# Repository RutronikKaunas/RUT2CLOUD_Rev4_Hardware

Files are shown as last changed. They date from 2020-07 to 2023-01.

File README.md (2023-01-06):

# RUT2CLOUD Evaluation Kit STM32WB55

This is the unreleased Rutronik development kit RUT2CLOUD Rev4. This board is featuring the GL865-DUAL 2G modem which is bundled together with the SL876Q5-A GNSS module and an STM32WB55 system-on-chip microcontroller that acts as a host of the system.

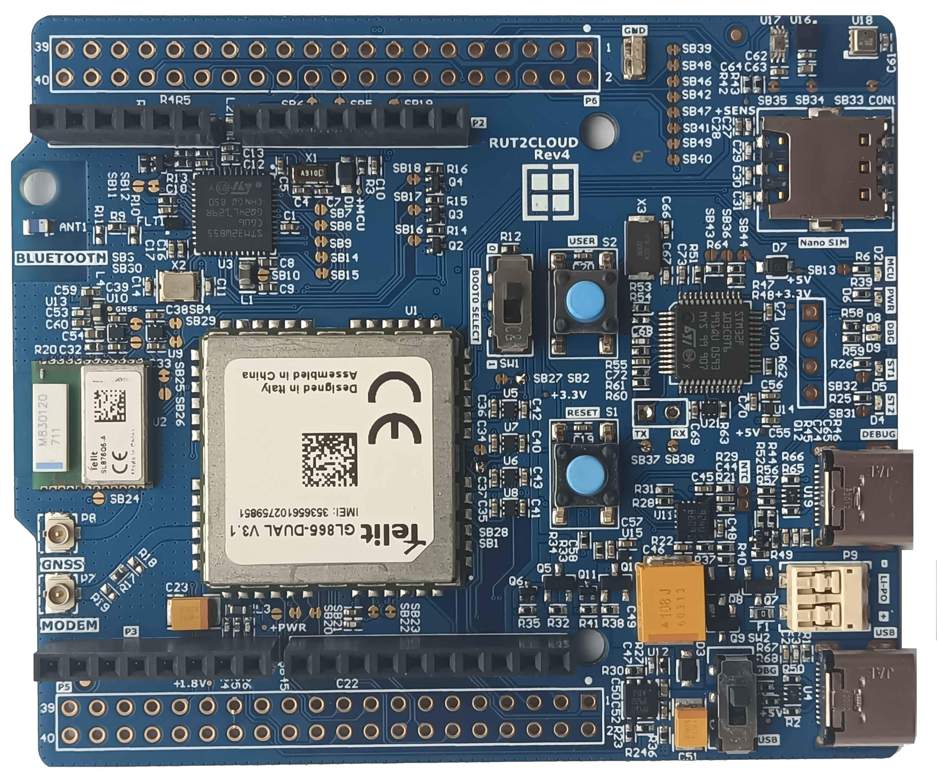
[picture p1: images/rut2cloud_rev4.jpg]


## Features

-   Telit GL865 DUAL V3.1 Cellular Modem (NL865 4G optional).
-   Telit SL876Q5-A GNSS Module.
-   Nano SIM card slot.
-   Ceramic Chip BLE Antenna ANT2012LL00R2400A.
-   STM32WB55CGU6 - Multiprotocol wireless 32-bit MCU Arm®-based Cortex®-M4  with FPU, Bluetooth® 5 and 802.15.4 radio solution.
-   L6924U - USB-compatible battery charger system with integrated power switch for Li-Ion/Li-Polymer.
-  LD39200PUR - 2 A high PSRR ultra-low drop linear regulator with reverse current protection.
-  STLQ020J18R - 1.8V 200 mA ultra-low quiescent current LDO.
-  STLQ020J33R – 3.3V 200 mA ultra-low quiescent current LDO.
-   LIS2DW12TR - MEMS digital output motion sensor: high-performance ultra-low-power 3-axis  "femto" accelerometer.
-   BH1730FVC-TR - Digital 16bit Serial Output Type  Ambient Light Sensor IC.
-   BME280 - Pressure, Humidity, Temperature Sensor.
-  
   Onboard ST-Link Debugger.

## Legal Disclaimer

The evaluation board including the software is for testing purposes only and, because it has limited functions and limited resilience, is not suitable for permanent use under real conditions. If the evaluation board is nevertheless used under real conditions, this is done at one’s responsibility; any liability of Rutronik is insofar excluded. 

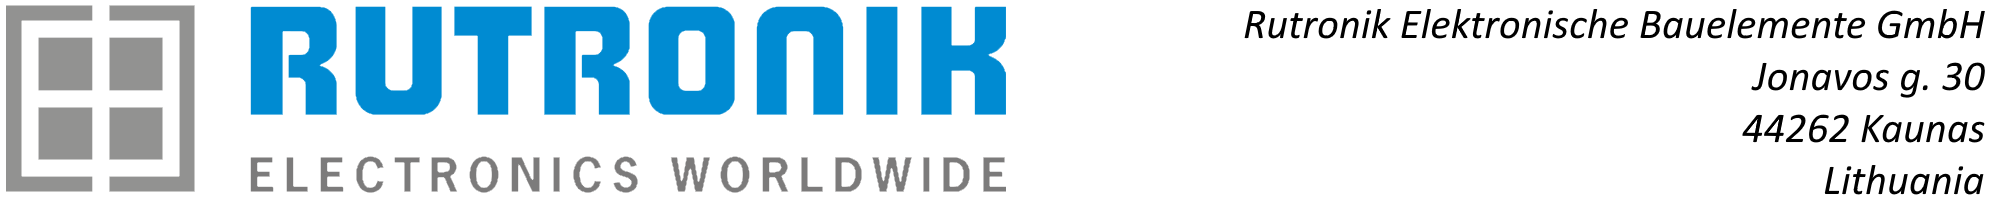
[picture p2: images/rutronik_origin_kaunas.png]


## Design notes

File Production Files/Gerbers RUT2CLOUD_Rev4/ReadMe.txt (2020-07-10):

Project RUT2CLOUD_Rev4:
PCB dimensions 82x82.5mm.
4 Layers.
Thickness: 1.55 mm. FR4
Mask color : Blue.
Silkscreen color: White.
Finish: Immersion GOLD

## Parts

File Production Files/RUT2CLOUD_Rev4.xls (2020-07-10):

 | RUT2CLOUD BOM Rev4
Part Description | Designator | Value | Footprint | Quantity | Manufacturer | Manufacturer Part No. | Specification | Supplier | Supplier part number | Link
Ceramic Chip Antenna | ANT1 | ANT2012LL00R2400A | YEGEO_BT_Antena_0805 | 1 | YAGEO | ANT2012LL00R2400A | 2.4 – 2.5 GHZ | Rutronik | WIREAC1413 | https://www.rutronik24.com/product/yageo/ant2012ll00r2400a/42235.html
Ceramic Capacitor | C1, C5, C13, C15, C16, C18, C21, C25, C28, C32, C33, C34, C35, C36, C37, C38, C39, C40, C41, C42, C43, C61, C62, C64, C69, C70, C71, C72, C73 | 220nF | C0402 | 29 | YAGEO | CC0402JRNPO9BN100, CC0402KRX5R5BB224 | NP0, 6.3V, 5%, X5R, 6.3V, 10% | Rutronik | KKK14556, KKK23148 | https://www.rutronik24.com/product/yageo/cc0402jrnpo9bn100/29735.html, https://www.rutronik24.com/product/yageo/cc0402krx5r5bb224/3611951.html
Ceramic Capacitor | C2, C74 | 4.7nF | C0402 | 2 | YAGEO | CC0402JRNPO9BN100 | NP0, 6.3V, 5% | Rutronik | KKK14556 | https://www.rutronik24.com/product/yageo/cc0402jrnpo9bn100/29735.html
Ceramic Capacitor | C3, C22, C24, C26, C27, C29, C30, C31, C53, C65 | 33pF | C0402 | 10 | YAGEO, AVX | CC0402JRNPO9BN100, 04025A330JAT2A | NP0, 6.3V, 5% | Rutronik | KKK14556, KKK13594 | https://www.rutronik24.com/product/yageo/cc0402jrnpo9bn100/29735.html, https://www.rutronik24.com/product/avx/04025a330jat2a/3692730.html
Ceramic Capacitor | C4, C7, C11, C14, C47 | 10pF | C0402 | 5 | YAGEO | CC0402JRNPO9BN100 | NP0, 6.3V, 5% | Rutronik | KKK14556 | https://www.rutronik24.com/product/yageo/cc0402jrnpo9bn100/29735.html
Ceramic Capacitor | C8, C9 | 4.7uF | C0402 | 2 | YAGEO | CC0402JRNPO9BN100 | NP0, 6.3V, 5% | Rutronik | KKK14556 | https://www.rutronik24.com/product/yageo/cc0402jrnpo9bn100/29735.html
Ceramic Capacitor | C10 | 100nF | C0402 | 1 | YAGEO | CC0402JRNPO9BN100 | NP0, 6.3V, 5% | Rutronik | KKK14556 | https://www.rutronik24.com/product/yageo/cc0402jrnpo9bn100/29735.html
Ceramic Capacitor | C12, C17 | 100pF | C0402 | 2 | YAGEO | CC0402JRNPO9BN100 | NP0, 6.3V, 5% | Rutronik | KKK14556 | https://www.rutronik24.com/product/yageo/cc0402jrnpo9bn100/29735.html
Ceramic Capacitor | C19, C20, C46 | 10nF | C0402 | 3 | Samsung Electronics | CL05B103KB5NNNC, CL05B102KB5NNND | X5R, 6.3V, 10% | Rutronik | KKK21418, KKK22306 | https://www.rutronik24.com/product/samsung+em/cl05b103kb5nnnc/6075254.html, https://www.rutronik24.com/product/samsung+em/cl05b102kb5nnnd/7450031.html
Tantalum Capacitor | C23, C51 | 100uF | Case-B | 2 | AVX | TPSB107K006R0400 | 6,3V 20% | Rutronik | KTA5959 | https://www.rutronik24.com/product/avx/tpsb107k006r0400/3688840.html
Ceramic Capacitor | C44, C45, C48, C52, C55, C56, C57, C58, C59, C60 | 1uF | C0402 | 10 | Samsung Electronics | CL05B102KB5NNND, CL05A106MP5NUNC, CL05A225MQ5NNNC | X5R, 6.3V, 10%, X5R, 6.3V, 20% | Rutronik | KKK22306, KKS2857, KKS2678 | https://www.rutronik24.com/product/samsung+em/cl05b102kb5nnnd/7450031.html, https://www.rutronik24.com/product/samsung+em/cl05a106mp5nunc/32408.html, https://www.rutronik24.com/product/samsung+em/cl05a225mq5nnnc/32280.html
Tantalum Capacitor | C49 | 1000uFx6.3V | 7361-38 | 1 | AVX | TPSV108M006R0050 | 6,3V 20% | Rutronik | TPSV108M006R0050 | https://www.rutronik24.com/product/avx/tpsv108m006r0050/11647835.html
Ceramic Capacitor | C50, C54, C63 | 10uF | C0402 | 3 | Samsung Electronics, YAGEO | CL05A106MP5NUNC, CC0402KRX5R5BB224 | X5R, 6.3V, 20%, X5R, 6.3V, 10% | Rutronik | KKS2857, KKK23148 | https://www.rutronik24.com/product/samsung+em/cl05a106mp5nunc/32408.html, https://www.rutronik24.com/product/yageo/cc0402krx5r5bb224/3611951.html
Ceramic Capacitor | C66, C67, C68 | 20pF | C0402 | 3 | YAGEO | CC0402JRNPO9BN100 | NP0, 6.3V, 5% | Rutronik | KKK14556 | https://www.rutronik24.com/product/yageo/cc0402jrnpo9bn100/29735.html
Nano SIM Card Connector | CON1 | CH03-KB060-HAR | CH03-KB | 1 | GradConn | CH03-KB060-HAR | Nano, 6 pins | Rutronik | SIMCRD1002 | https://www.rutronik24.com/product/gradconn/ch03-kb060-har/7026333.html
Low VF Schottky Barrier Rectifier | D1, D3, D7 | RB168VAM-30 | SOD323 | 3 | ROHM | RB168VAM-30 | 30V, 1A | Rutronik | RB168VAM-30 | http://rohmfs.rohm.com/en/products/databook/datasheet/discrete/diode/schottky_barrier/rb168vam-30tr-e.pdf
Typical SMD LED | D2, D4, D6, D9 | SML-P13PTT86R | PICOLED | 4 | ROHM | SML-P13PTT86R | Green, 20mA | Rutronik | LED26047 | https://www.rutronik24.com/product/rohm/sml-p13ptt86r/11064312.html
Typical SMD LED | D5, D8 | SML-P12UTT86 | PICOLED | 2 | ROHM | SML-P12UTT86 | Red, 20mA | Rutronik | LED24884 | https://www.rutronik24.com/product/rohm/sml-p12utt86/8485748.html
Thick Film Resistor | F1 | 0R | R0603 | 1 | YAGEO | RC0402FR-070RL | 5% 0,063W | Rutronik | WRC53079 | https://www.rutronik24.com/product/yageo/rc0402fr-070rl/5183530.html
2.4 GHz low pass filter | FLT1 | MLPF-WB55-01E3 | Bumpless CSP | 1 | STMicroelectronics | MLPF-WB55-01E3 | 2.4GHz, CSP | Digi-Key | 497-19088-1-ND | https://www.digikey.com/product-detail/en/stmicroelectronics/MLPF-WB55-01E3/497-19088-1-ND/10057128
Inductor | L1 | 10uH | L0805 | 1 | muRata | LQM21FN100M70L | 100mA | Rutronik | IND8474 | https://www.rutronik24.com/product/murata/lqm21fn100m70l/25672.html
Ferrite Bead | L2, L3, L4 | BLM18PG121SH1D | L0603 | 3 | muRata | BLM18PG121SH1D | 120R, 2A | Rutronik | FE3867 | https://www.rutronik24.com/product/murata/blm18pg121sh1d/5885588.html
Arduino Stackable Header Kit | P1 | PRT-11417 | HDR1X10 | 1 | SparkFun Electronics | PRT-11417 | 10 pins | Digi-Key | 1568-1413-ND
U.FL Connector | P7, P8 | U.FL-R-SMT-1(10) | U.FL_Connector_Male | 2 | HIROSE | U.FL-R-SMT-1(10) | Male | Rutronik | COREC23028 | https://www.hirose.com/product/en/products/U.FL/U.FL-R-SMT-1%2810%29/
Terminal | P9 | 104238-0210 | 104238-0210 Molex | 1 | Molex | 104238-0210 | 2 pins, 5 mm pitch | Rutronik | COREC38239 | https://www.molex.com/molex/products/datasheet.jsp?part=active/1042380210_PCB_RECEPTACLES.xml
24P USB C DUAL SMT ON BOARD | P12, P13 | DX07S024JJ2R1300 | DX07_USB_C | 2 | JAE | DX07S024JJ2R1300 | Type C | Rutronik | CONIO1808 | https://www.rutronik24.com/product/jae/dx07s024jj2r1300/8301548.html
N-Channel MOSFET | Q1, Q2, Q3, Q4, Q6, Q11 | DMG1012T-7 | SOT-523_custom | 6 | Diodes Inc. | DMG1012T-7 | 20V, 0.63A | Rutronik | TMOSS6623 | https://www.rutronik24.com/product/diodes+inc/dmg1012t-7/5168665.html
P-Channel MOSFET | Q5, Q7, Q8, Q9, Q10 | DMP3099L-7 | SOT23_custom | 5 | Diodes Inc. | DMP3099L-7 | -30V, -3.8A | Rutronik | TMOSS6836 | https://www.rutronik24.com/product/diodes+inc/dmp3099l-7/5168905.html
45V NPN SMALL SIGNAL TRANSISTOR | Q12 | BC847AT-7-F | SOT-523_custom | 1 | Diodes Inc. | BC847AT-7-F | 45V, 0.1A | Rutronik | BC847AT-7-F | https://www.rutronik24.com/product/diodes+inc/bc847at-7-f/11676160.html
Thick Film Resistor | R1, R37, R46 | 1M | R0402 | 3 | YAGEO, ASJ | RC0402FR-070RL, CR10-105-JK | 5% 0,063W | Rutronik | WRC53079, WRC35254 | https://www.rutronik24.com/product/yageo/rc0402fr-070rl/5183530.html, https://www.rutronik24.com/product/asj/cr10-105-jk/51971.html
Thick Film Resistor | R2, R50, R65, R66 | 5.1K | R0402 | 4 | ASJ | CR10-103-JK | 5% 0,063W | Rutronik | WRC40976 | https://www.rutronik24.com/product/asj/cr10-103-jk/54295.html
Thick Film Resistor | R3, R23, R51, R55, R63 | 100K | R0402 | 5 | ASJ | CR10-103-JK, CR10-104-JK | 5% 0,063W | Rutronik | WRC40976, WRC34858 | https://www.rutronik24.com/product/asj/cr10-103-jk/54295.html, https://www.rutronik24.com/product/asj/cr10-104-jk/51752.html
Thick Film Resistor | R4, R28 | 12K | R0402 | 2 | ASJ | CR10-105-JK, CR10-471-JK | 5% 0,063W | Rutronik | WRC35254, WRC41425 | https://www.rutronik24.com/product/asj/cr10-105-jk/51971.html, https://www.rutronik24.com/product/asj/cr10-471-jk/54391.html
Thick Film Resistor | R5, R21, R25, R26 | 1K | R0402 | 4 | ASJ | CR10-102-JK, CR10-471-JK | 5% 0,063W | Rutronik | WRC41426, WRC41425 | https://www.rutronik24.com/product/asj/cr10-102-jk/54392.html, https://www.rutronik24.com/product/asj/cr10-471-jk/54391.html
Thick Film Resistor | R6, R40 | 220R | R0402 | 2 | ASJ | CR10-221-JK | 5% 0,063W | Rutronik | WRC35108 | https://www.rutronik24.com/product/asj/cr10-221-jk/51883.html
Thick Film Resistor | R7 | 30K | R0402 | 1 | YAGEO | RC0402JR-07390KL | 5% 0,063W | Rutronik | WRC33888 | https://www.rutronik24.com/product/yageo/rc0402jr-07390kl/51055.html
Thick Film Resistor | R8, R12, R14, R15, R16, R20, R24, R27, R44, R53 | 10K | R0402 | 10 | ASJ | CR10-103-JK | 5% 0,063W | Rutronik | WRC40976 | https://www.rutronik24.com/product/asj/cr10-103-jk/54295.html
Thick Film Resistor | R9, R13, R17, R33, R34, R36, R64 | 0R | R0402 | 7 | YAGEO, ASJ | RC0402FR-070RL, CR10-103-JK | 5% 0,063W | Rutronik | WRC53079, WRC40976 | https://www.rutronik24.com/product/yageo/rc0402fr-070rl/5183530.html, https://www.rutronik24.com/product/asj/cr10-103-jk/54295.html
Thick Film Resistor | R22, R39 | 470R | R0402 | 2 | ASJ | CR10-471-JK | 5% 0,063W | Rutronik | WRC41425 | https://www.rutronik24.com/product/asj/cr10-471-jk/54391.html
Thick Film Resistor | R29 | 2.2K | R0402 | 1 | ASJ | CR10-471-JK | 5% 0,063W | Rutronik | WRC41425 | https://www.rutronik24.com/product/asj/cr10-471-jk/54391.html
Thick Film Resistor | R30 | 1.5K | R0402 | 1 | YAGEO | RC0402JR-071K5L | 5% 0,063W | Rutronik | WRC33836 | https://www.rutronik24.com/product/yageo/rc0402jr-071k5l/51006.html
Thick Film Resistor | R31 | 25.5K | R0402 | 1 | ASJ | CR10-471-JK | 5% 0,063W | Rutronik | WRC41425 | https://www.rutronik24.com/product/asj/cr10-471-jk/54391.html
Thick Film Resistor | R32, R35, R38, R41 | 470K | R0402 | 4 | ASJ | CR10-474-JK | 5% 0,063W | Rutronik | WRC35429 | https://www.rutronik24.com/product/asj/cr10-474-jk/52065.html
Thick Film Resistor | R42, R43 | 4.7K | R0402 | 2 | ASJ | CR10-472-JK | 5% 0,063W | Rutronik | WRC41427 | https://www.rutronik24.com/product/asj/cr10-472-jk/54393.html
Thick Film Resistor | R45, R58, R59, R62 | 100 | R0402 | 4 | ASJ | CR10-103-JK | 5% 0,063W | Rutronik | WRC40976 | https://www.rutronik24.com/product/asj/cr10-103-jk/54295.html
Thick Film Resistor | R47 | 2K7 | R0402 | 1 | ASJ | CR10-103-JK | 5% 0,063W | Rutronik | WRC40976 | https://www.rutronik24.com/product/asj/cr10-103-jk/54295.html
Thick Film Resistor | R48, R60, R61 | 4K7 | R0402 | 3 | ASJ | CR10-103-JK | 5% 0,063W | Rutronik | WRC40976 | https://www.rutronik24.com/product/asj/cr10-103-jk/54295.html
Thick Film Resistor | R49 | 36K | R0402 | 1 | ASJ | CR10-103-JK | 5% 0,063W | Rutronik | WRC40976 | https://www.rutronik24.com/product/asj/cr10-103-jk/54295.html
Thick Film Resistor | R52 | 1K5 | R0402 | 1 | ASJ | CR10-103-JK | 5% 0,063W | Rutronik | WRC40976 | https://www.rutronik24.com/product/asj/cr10-103-jk/54295.html
Thick Film Resistor | R56, R57, R67, R68 | 22R | R0402 | 4 | ASJ | CR10-103-JK | 5% 0,063W | Rutronik | WRC40976 | https://www.rutronik24.com/product/asj/cr10-103-jk/54295.html
Tactile Button | S1, S2 | PTS645SM43SMTR92 LFS | PTS645S_button | 2 | C&K | PTS645SM43SMTR92 LFS | 1.6N, Straight, SMT | Rutronik | SWITCH8818 | https://www.rutronik24.com/product/c%26k/pts645sm43smtr92+lfs/3580965.html
VERTICAL MOUNT SMT - J BEND | SW1, SW2 | JS202011JCQN | JS202011JCQN | 2 | CK Switches | JS202011JCQN | 6V DC, 0.3A | Rutronik | SWITCH10809 | https://www.ckswitches.com/media/1422/js.pdf
SMT Test Point | TP1 | 5019 | 5019_keystone | 1 | Keystone Electrincs | 5019 | 3.81*2.03 | Rutronik | BAT4950 | https://www.rutronik24.com/product/keystone/5019/7028403.html
Cellular Module | U1 | GL865-DUAL V3.1 | XL865XXX | 1 | Telit | GL865-DUAL V3.1 | Dual Band | Rutronik | GSM1755 | https://www.rutronik24.com/product/telit/gl865d31613t001/9566944.html
GNSS Embedded Module | U2 | SL876Q5-A | SL876Q5-A | 1 | Telit | SL876Q5-A | GPS, Glonass | Rutronik | GPS1354 | https://www.rutronik24.com/product/telit/sl876q5a001t001000/9723106.html
Multiprotocol wireless 32-bit MCU Arm®-based Cortex®-M4 with FPU, Bluetooth® 5 and 802.15.4 radio solution | U3 | STM32WB55CGU6 | UFQFPN48 | 1 | STMicroelectronics | STM32WB55CGU6 | 1MB Flash, 256K BRAM | Rutronik | STM32WB55CGU6 | https://www.st.com/en/microcontrollers-microprocessors/stm32wb55cg.html
Ultra large bandwidth ESD protection | U4, U19 | USBULC6-2M6 | Micro_QFN_6L | 2 | STMicroelectronics | USBULC6-2M6 | 6V, 0.6pF | Rutronik | DTRL11259 | https://www.rutronik24.com/product/st/usbulc6-2m6/3623499.html
Single Bit Voltage Level Translator | U5, U6, U7, U8, U9, U10 | 74LVC1T45FZ4-7 | X2-DFN1410-6 | 6 | Diodes Inc. | 74LVC1T45FZ4-7 | 5.5V, 1.65V | Rutronik | 74LVC1T45FZ4-7 | https://www.rutronik24.com/product/diodes+inc/74lvc1t45w6-7/7622634.html
USB compatible battery charger system with integrated power switch for Li-Ion/Li-Polymer | U11 | L6924U | VFQFPN16 | 1 | STMicroelectronics | L6924U | 12V, 1A, Li-PO | Rutronik | ICPWM6861 | https://www.rutronik24.com/product/st/l6924utr/8297844.html
2 A high PSRR ultra low drop linear regulator with reverse current protection | U12 | LD39200PUR | DFN6 | 1 | STMicroelectronics | LD39200PUR | 2A ADJ. | Rutronik | ICSPR10216 | https://www.rutronik24.com/product/st/ld39200pur/8309892.html
200 mA ultra-low quiescent current LDO | U13 | STLQ020J18R | Flip-Chip4 | 1 | STMicroelectronics | STLQ020J18R | 1.8V, 200mA | Rutronik | ICSPR10227 | https://www.rutronik24.com/product/st/stlq020j18r/10086303.html
200 mA ultra-low quiescent current LDO | U14, U15 | STLQ020J33R | Flip-Chip4 | 2 | STMicroelectronics | STLQ020J33R | 3.3V, 200mA | Rutronik | STLQ020J33R | https://www.rutronik24.com/product/st/stlq020j33r/12065124.html
MEMS digital output motion sensor: high-performance ultra-low-power 3-axis "femto" accelerometer | U16 | LIS2DW12TR | LGA-12 package | 1 | STMicroelectronics | LIS2DW12TR | 1.62V, 3.6V, 2-8g | Rutronik | ICMEMS1297 | https://www.rutronik24.com/product/st/lis2dw12tr/8441777.html
Digital 16bit Serial Output Type Ambient Light Sensor IC | U17 | BH1730FVC-TR | WSOF6 | 1 | ROHM | BH1730FVC-TR | 2.4V, 3.6V, 100klx | Rutronik | ICIN3260 | https://www.rutronik24.com/product/rohm/bh1730fvc-tr/5199695.html
Pressure, Humidity, tempereture Sensor | U18 | BME280 | BME280 | 1 | BOSH | BME280 | I2C, SPI, 3.6uA | Rutronik | ICIN3565 | https://www.rutronik24.com/product/bosch+se/bme280/6440107.html
ARM® Cortex®-M3 STM32F1 Microcontroller IC 32-Bit 72MHz 128KB (128K x 8) FLASH | U20 | STM32F103CBT6 | QFP48 7X7 | 1 | STMicroelectronics | STM32F103CBT6 | 128KB Flash, 20KB RAM | Rutronik | ICMCU17424 | https://www.rutronik24.com/product/st/stm32f103cbt6/18975.html
SINGLE BUFFER/DRIVER WITH OPEN DRAIN OUTPUT | U21 | 74LVC1G07FZ4-7 | X2-DFN1410-6 | 1 | STMicroelectronics | 74LVC1G07FZ4-7 | 5.5V, 1.65V | Rutronik | 74LVC1G07FZ4-7 | https://www.rutronik24.com/product/diodes+inc/74lvc1g07fz4-7/11672158.html
XTAL 3.2x1.5mm | X1 | FC-135 32.7680KA-AC3 | XTAL_3215 | 1 | Epson Electronics | FC-135 32.7680KA-AC3 | 32.768 kHz, 9pF, 20ppm | Rutronik | QUARZ6279 | https://www.rutronik24.com/product/epson/fc-135r+32%2C768khz++9pf++20ppm+++rohsconf/5825395.html
XTAL 3.2x2.5mm | X2 | CX3225SB32000D0FLJCC | XTAL_3.5x2.5 | 1 | Kyocera | CX3225SB32000D0FLJCC | 32MHz, 8pF, 15ppm | Rutronik | CX3225SB32000D0FLJCC | https://global.kyocera.com/prdct/electro/product/crystal-device/xtal/
XTAL 5.0x3.2mmm | X3 | CX5032GB08000H0HEQZ1 | crystal_5032 | 1 | Kyocera | CX5032GB08000H0HEQZ1 | 8MHz, 12pF, 20ppm | Rutronik | CX5032GB08000H0HEQZ1 | https://global.kyocera.com/prdct/electro/product/crystal-device/xtal/

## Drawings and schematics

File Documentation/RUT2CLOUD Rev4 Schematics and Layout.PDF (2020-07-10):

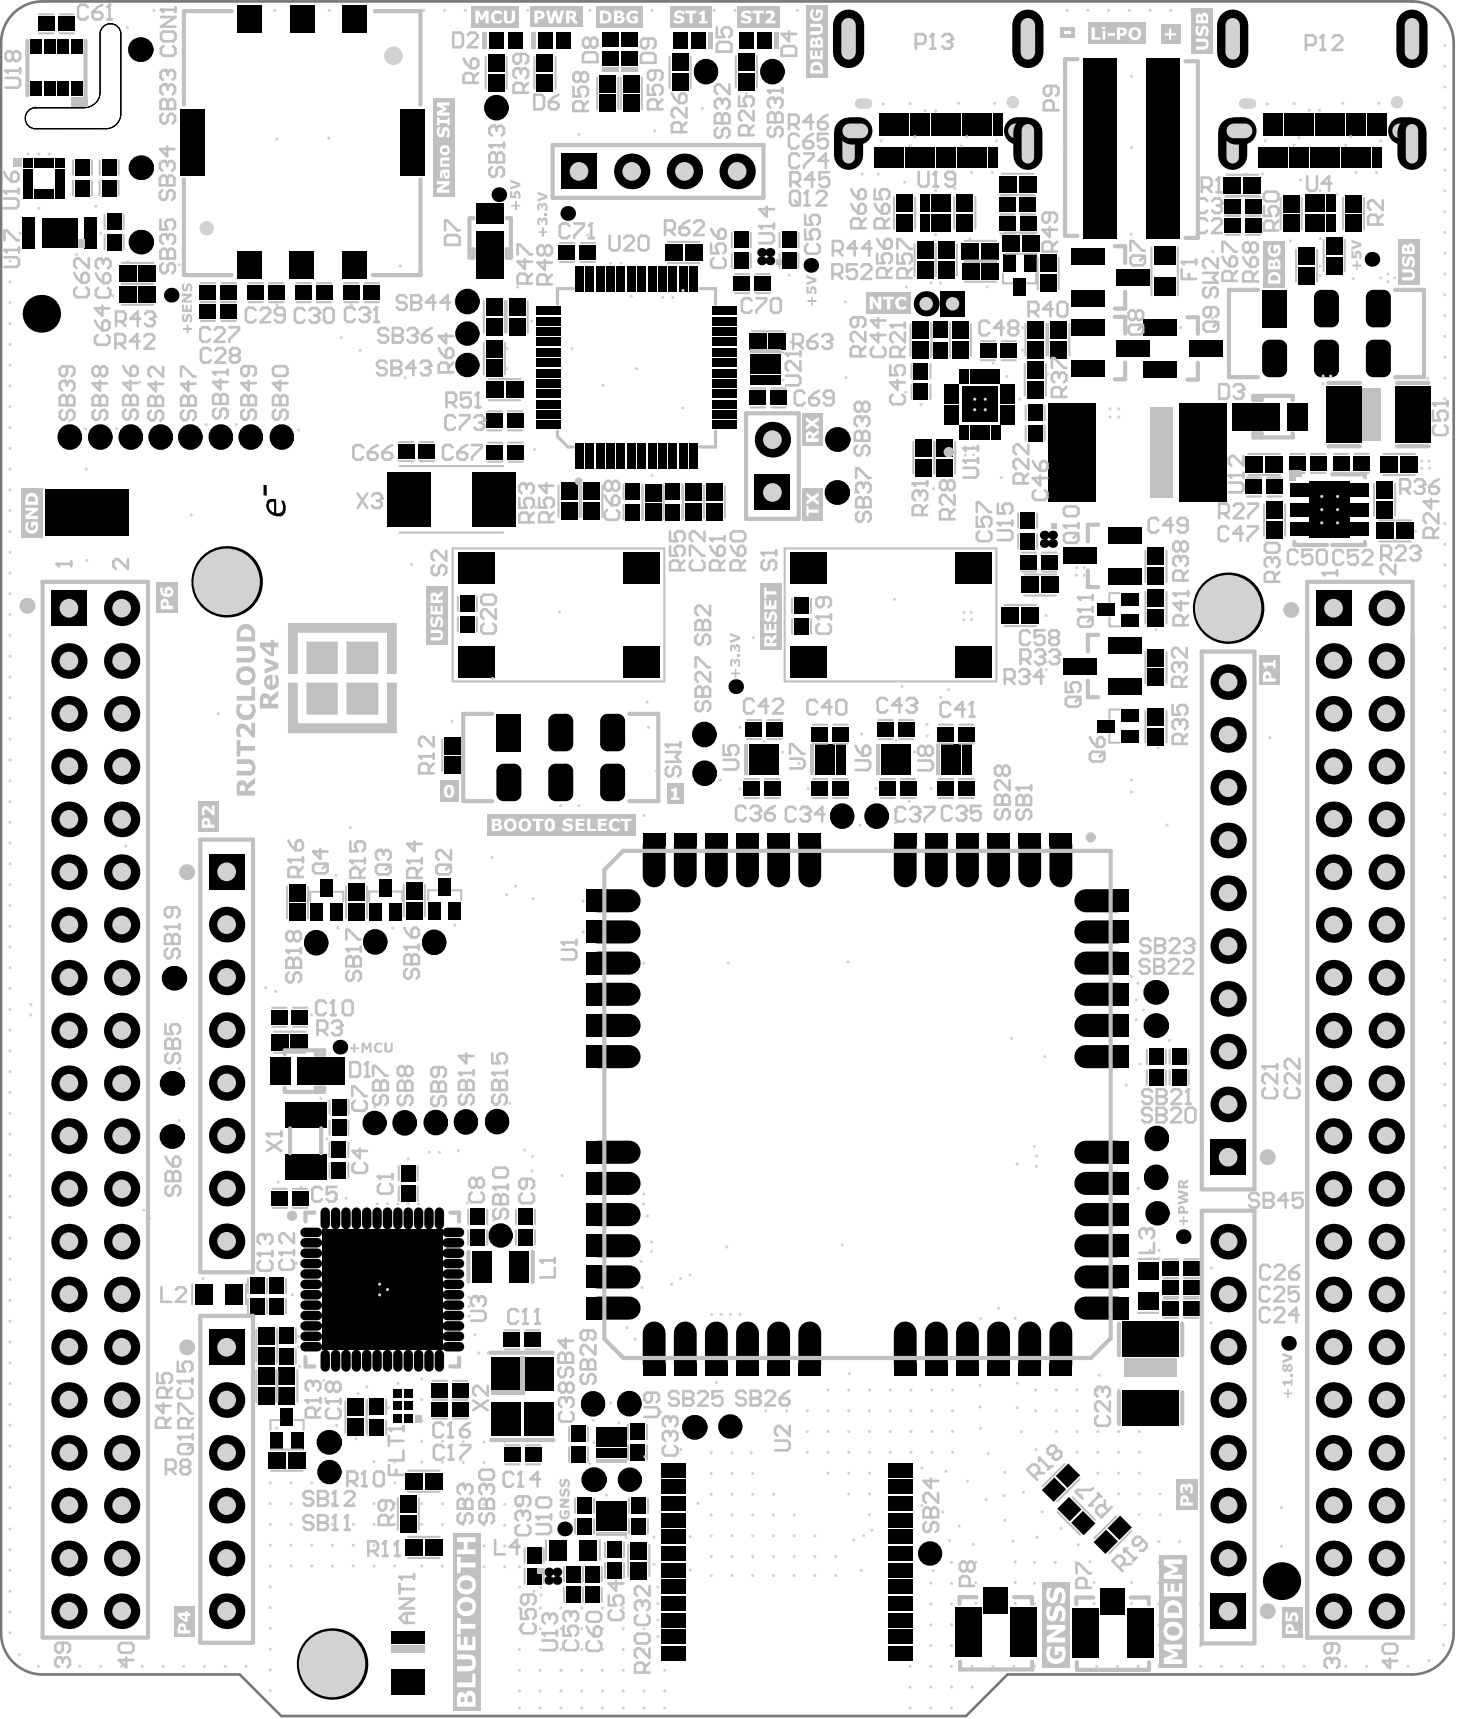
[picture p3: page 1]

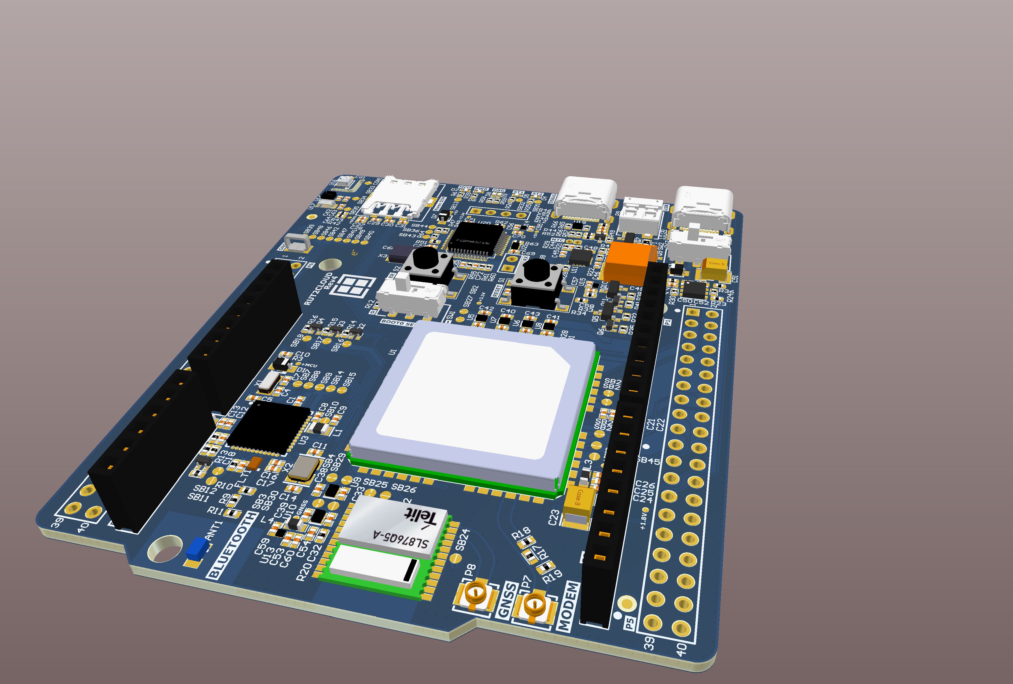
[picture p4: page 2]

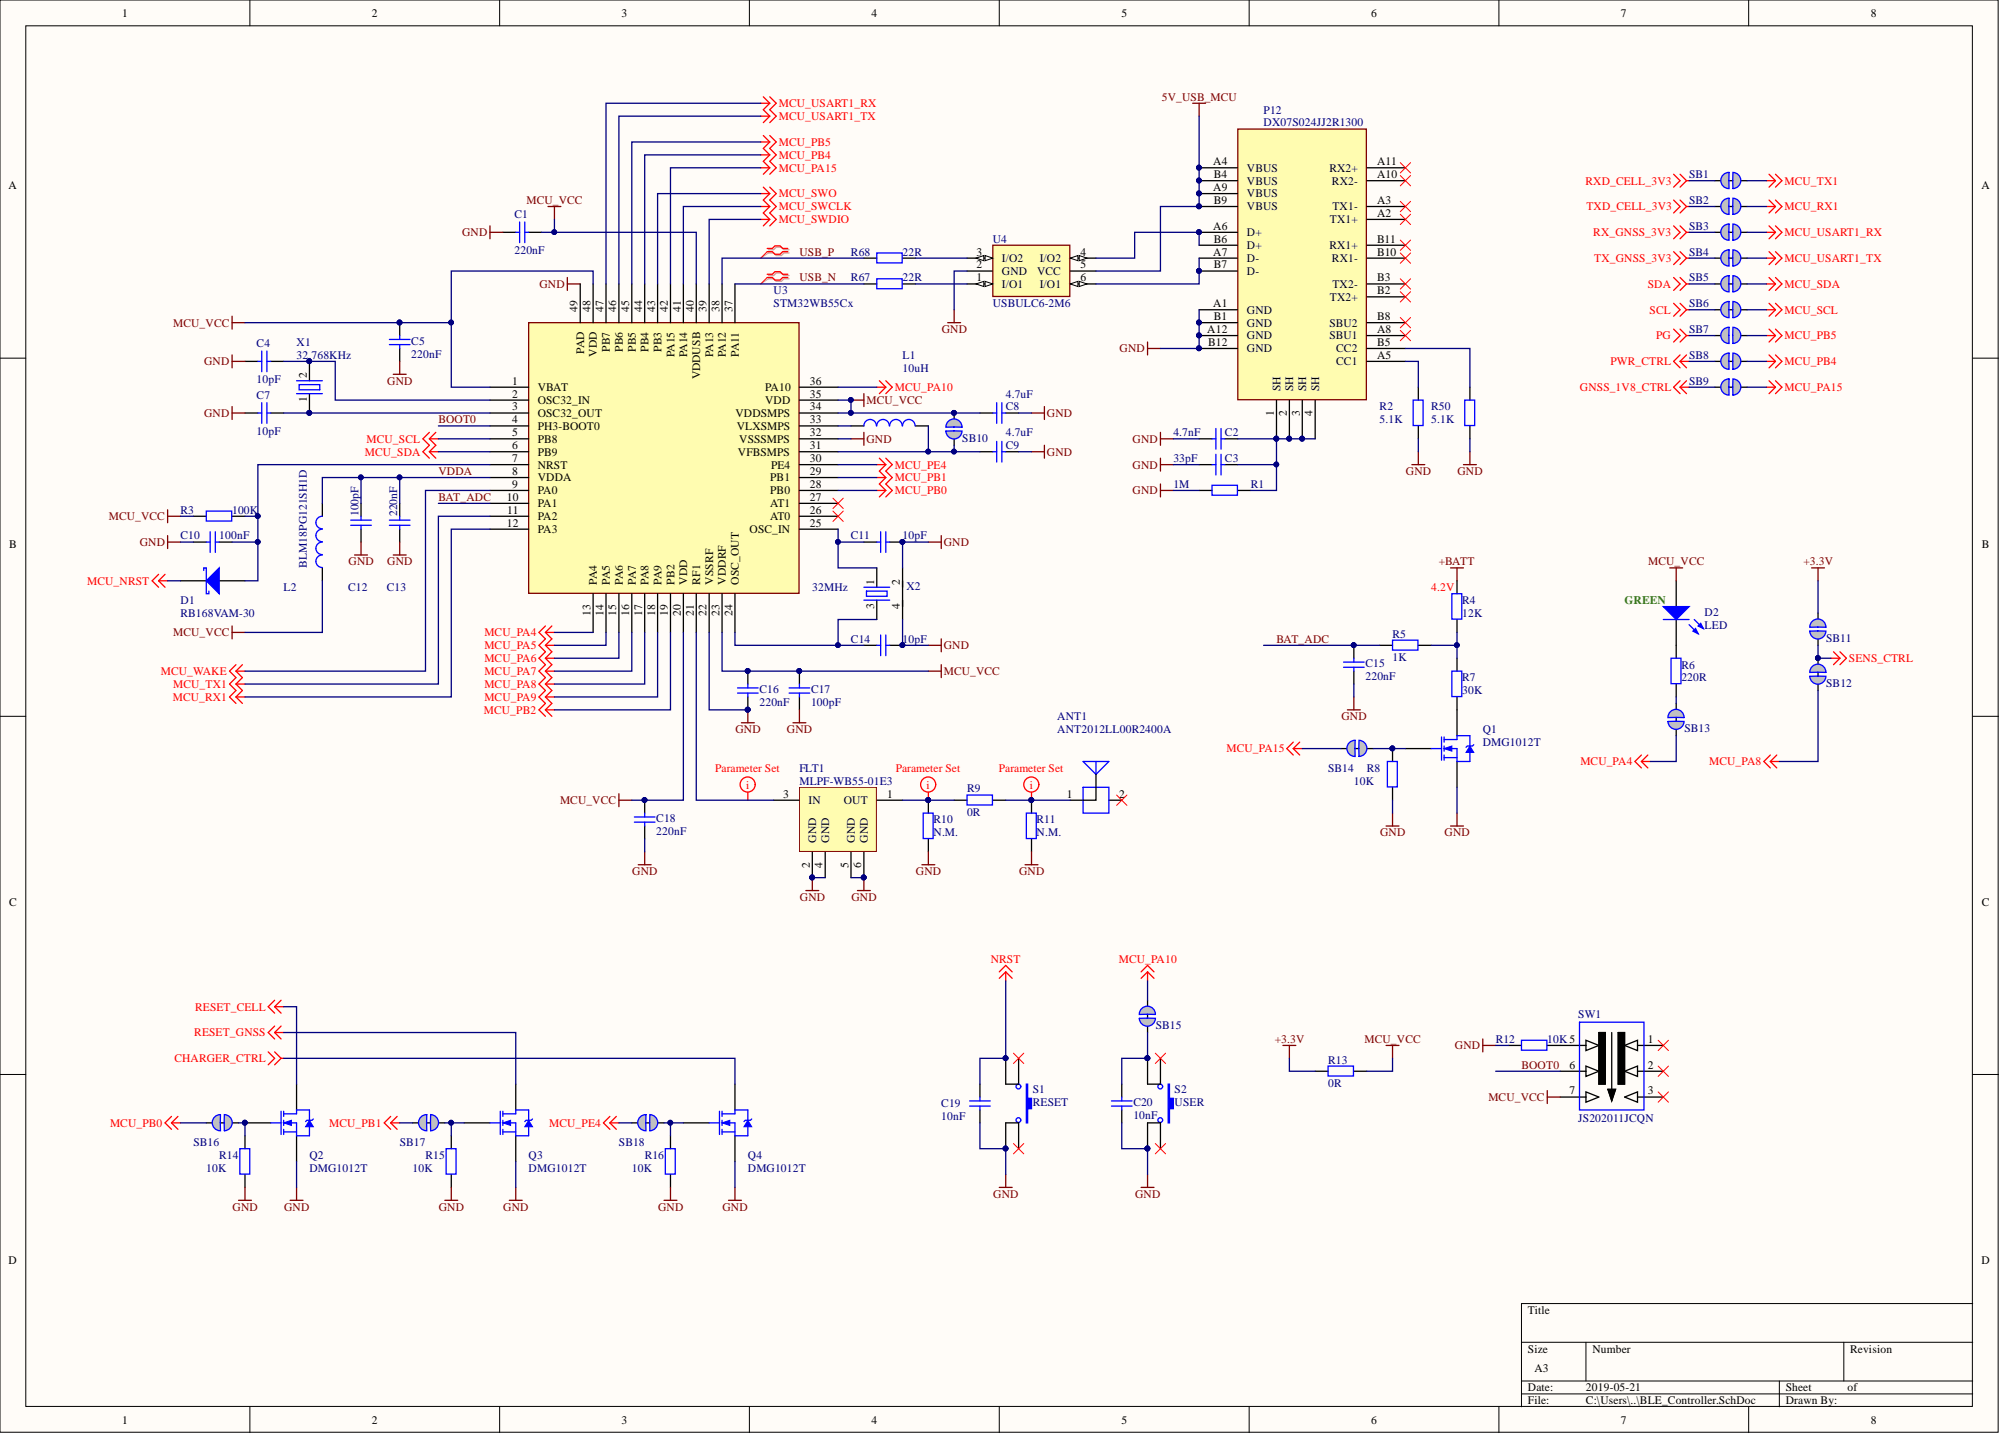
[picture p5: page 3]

BAT_ADC | PA1 10

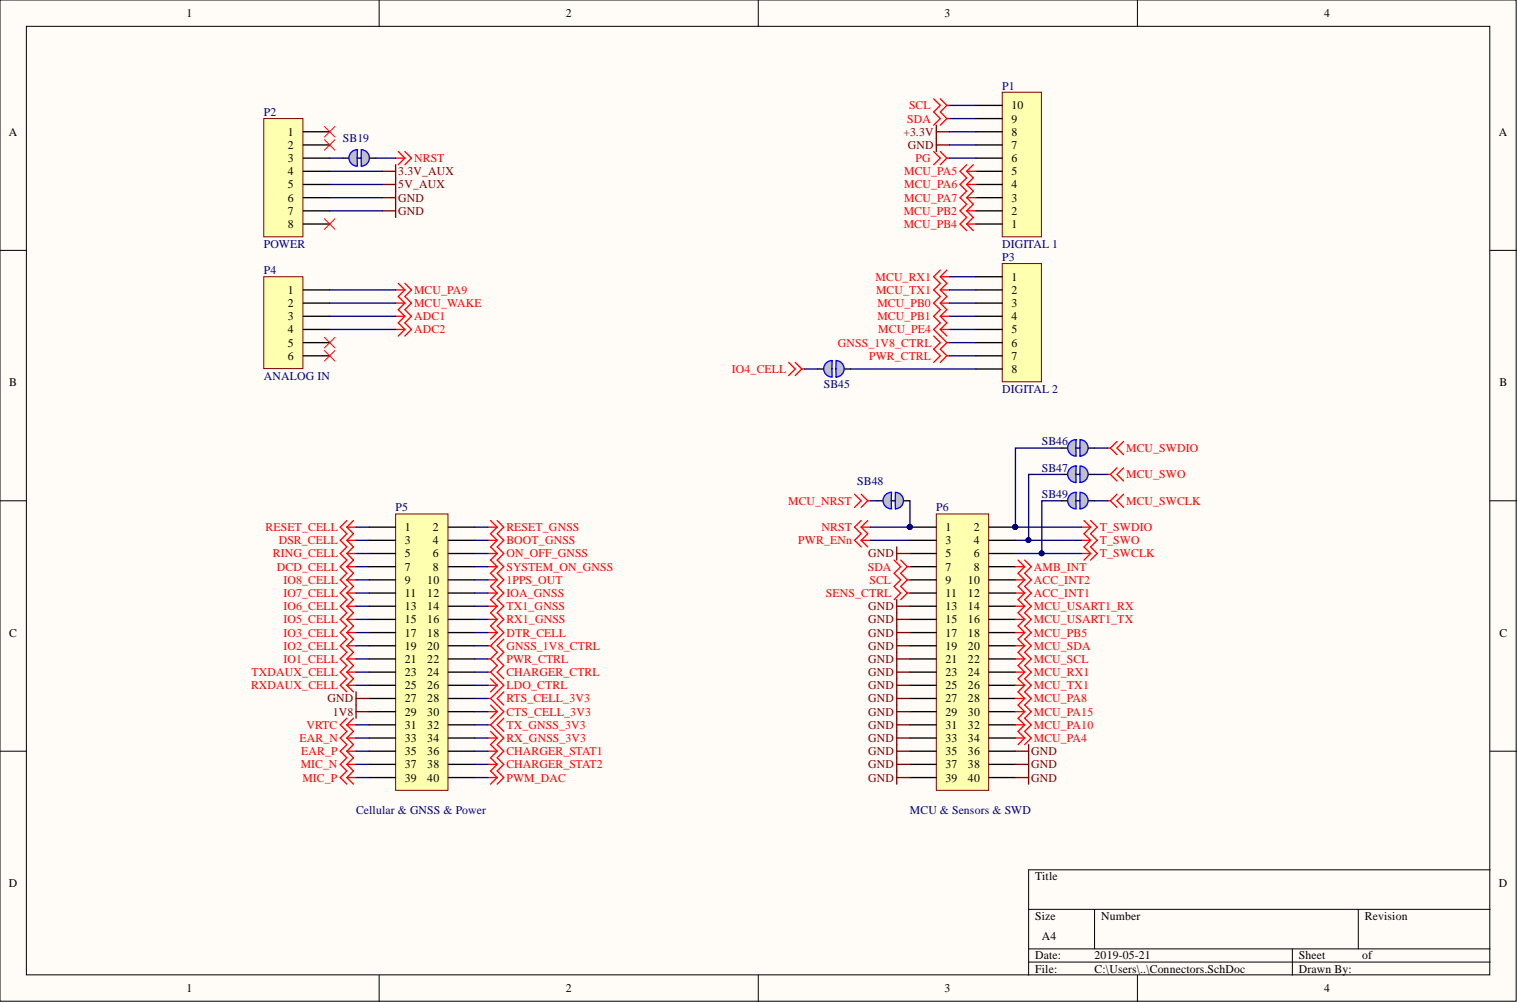
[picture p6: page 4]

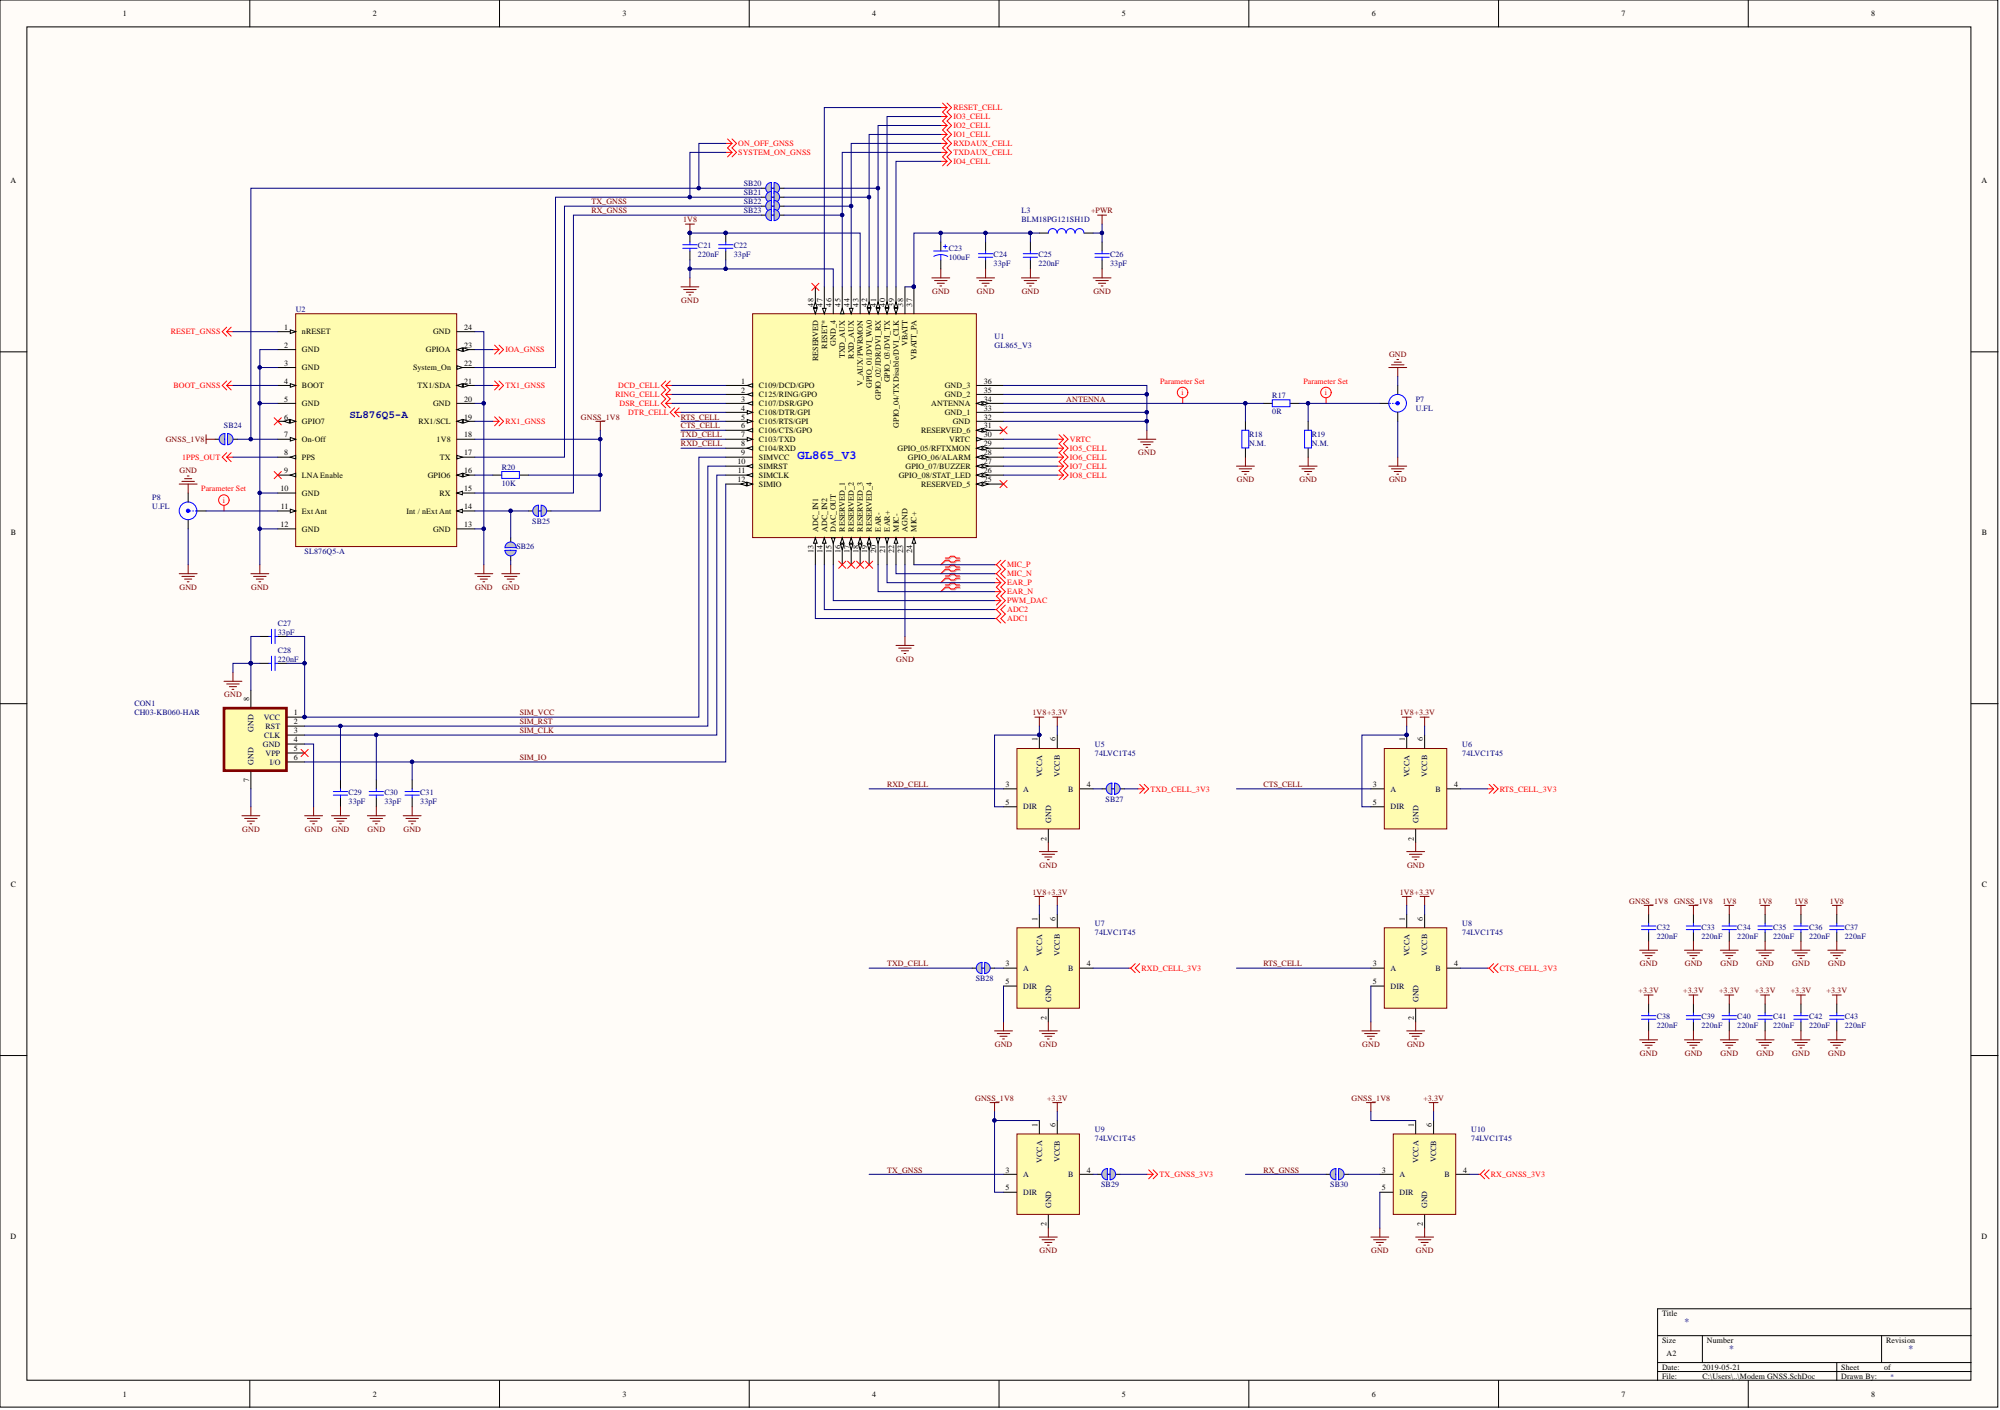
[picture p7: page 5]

SIMRST 10

GPIO6 | 16 | R20 | SIMIO 12 SIMCLK 11

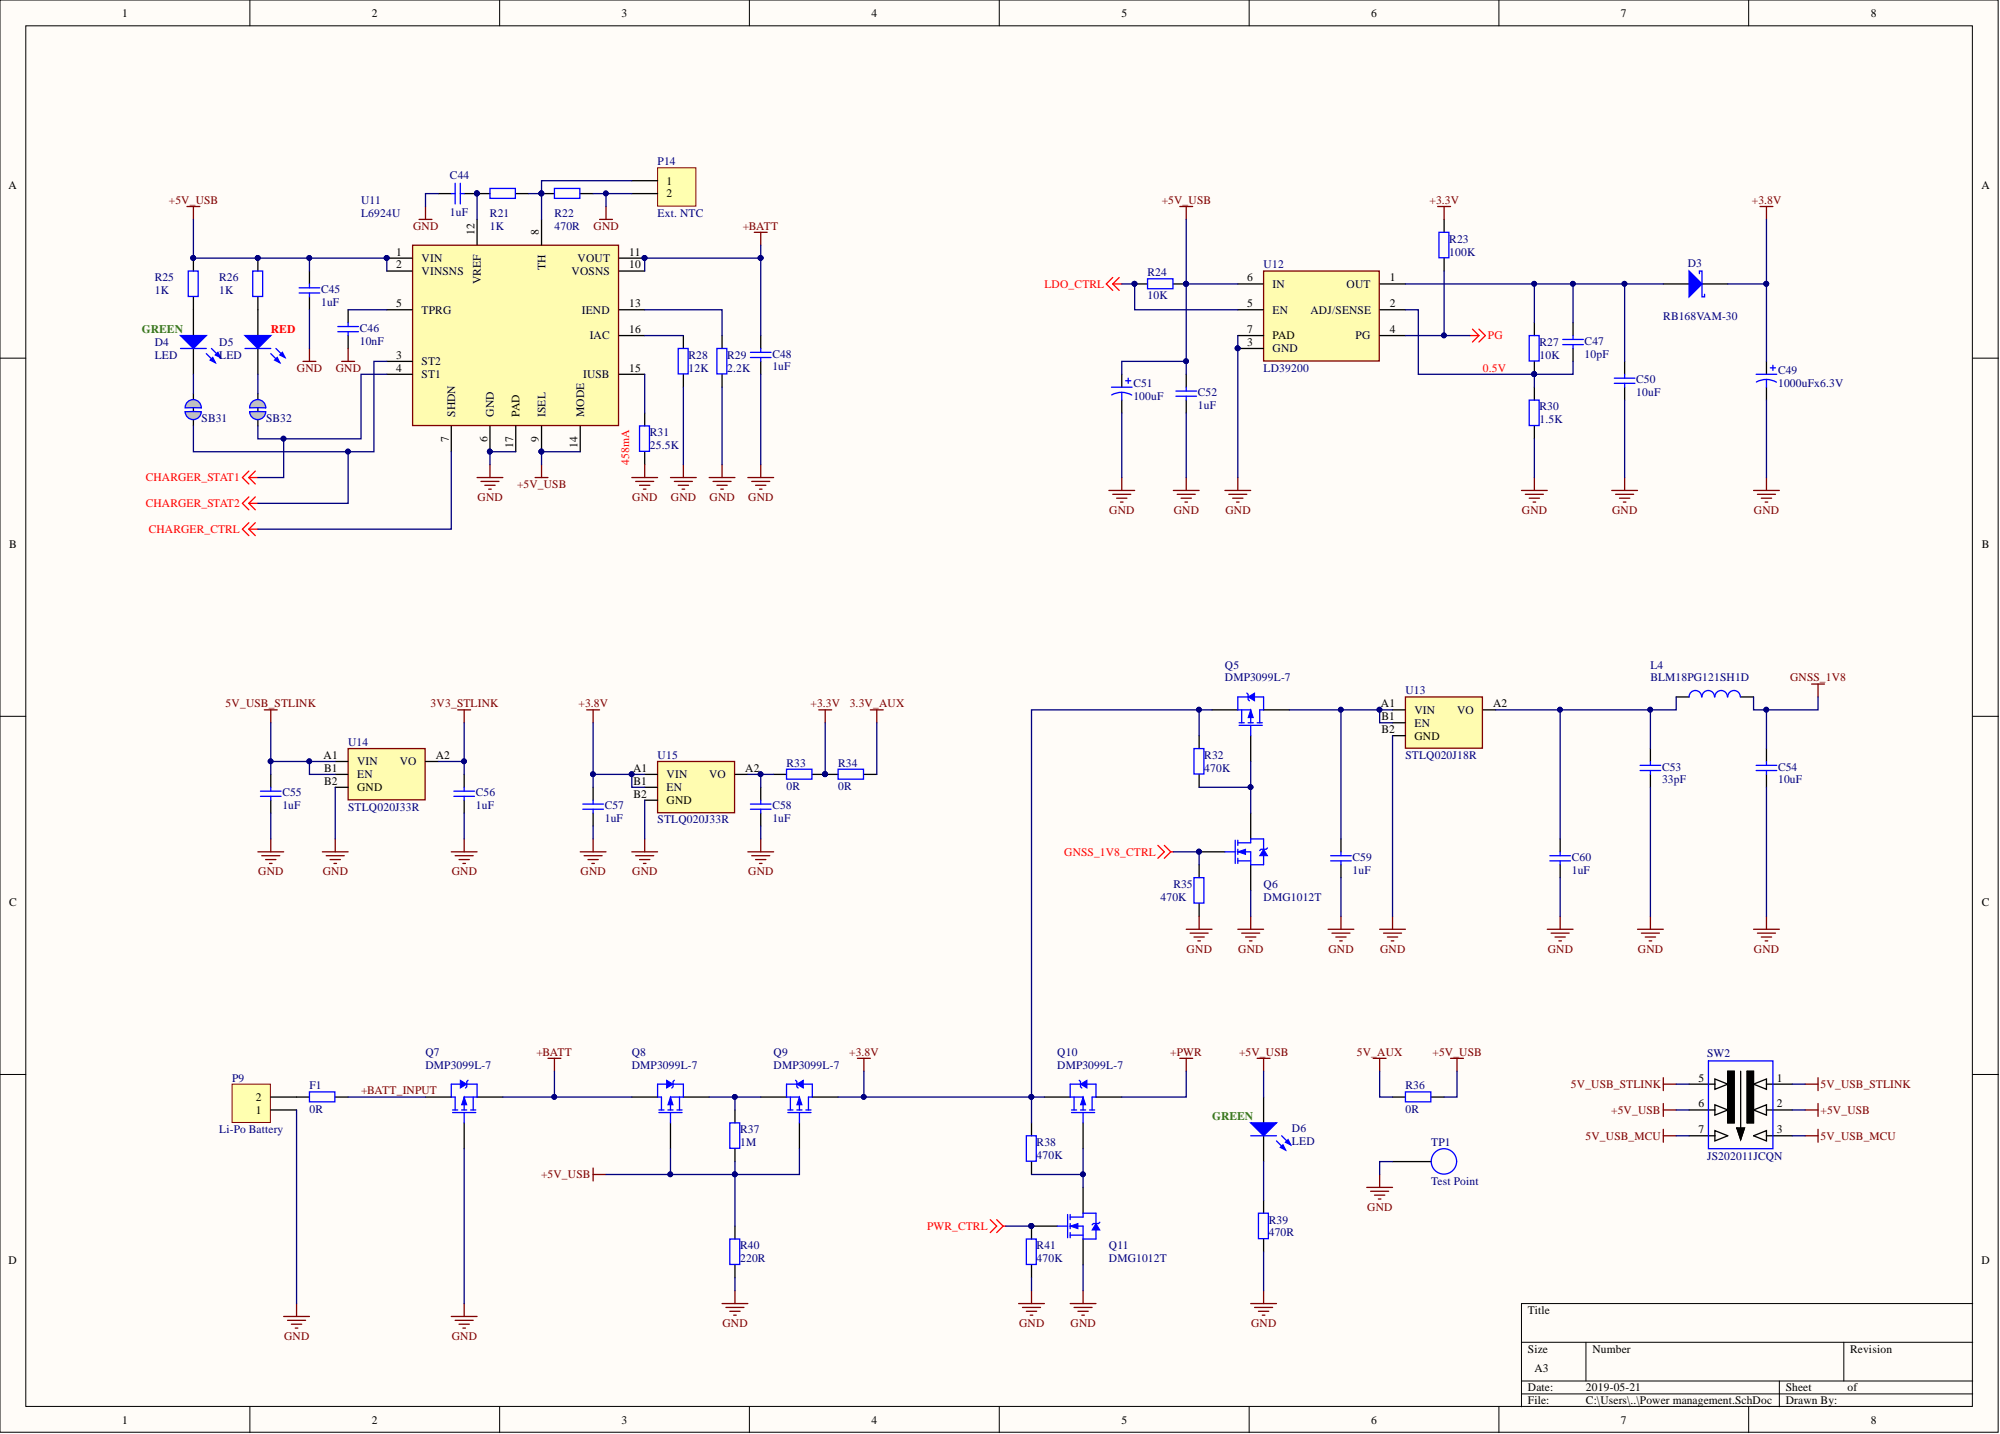
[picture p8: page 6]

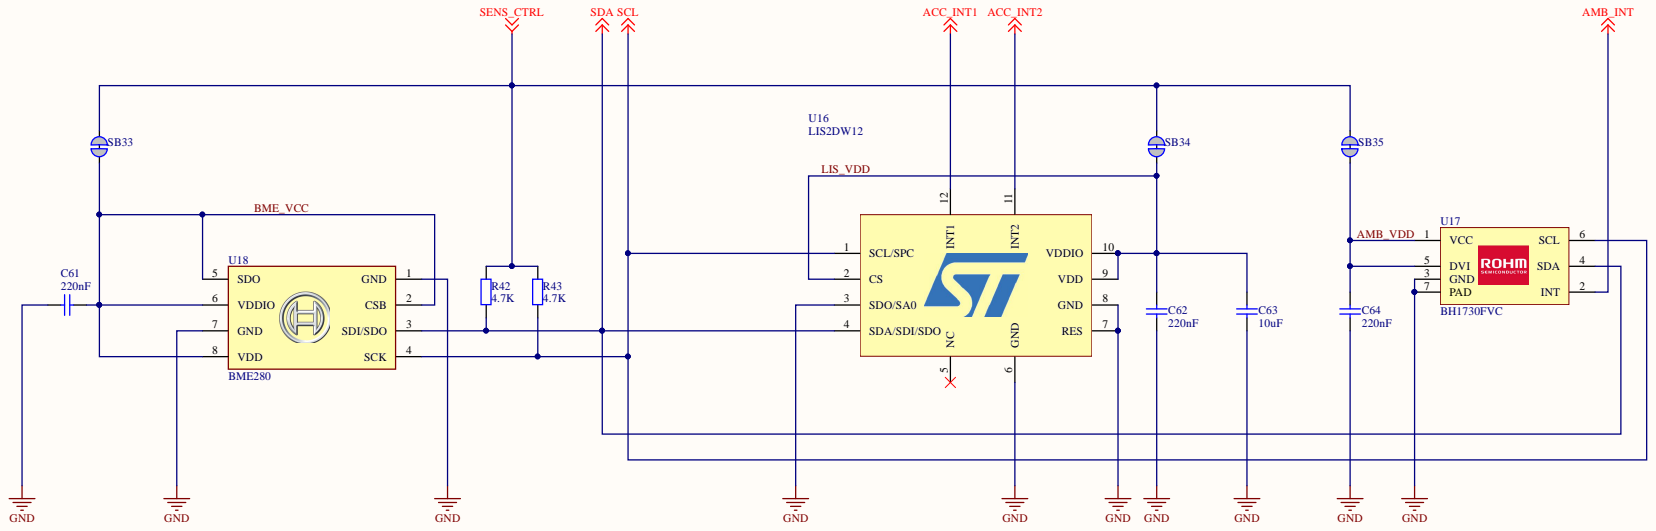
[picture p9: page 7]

U 1 6 LIS2 D W 1 2

LIS_ V D D

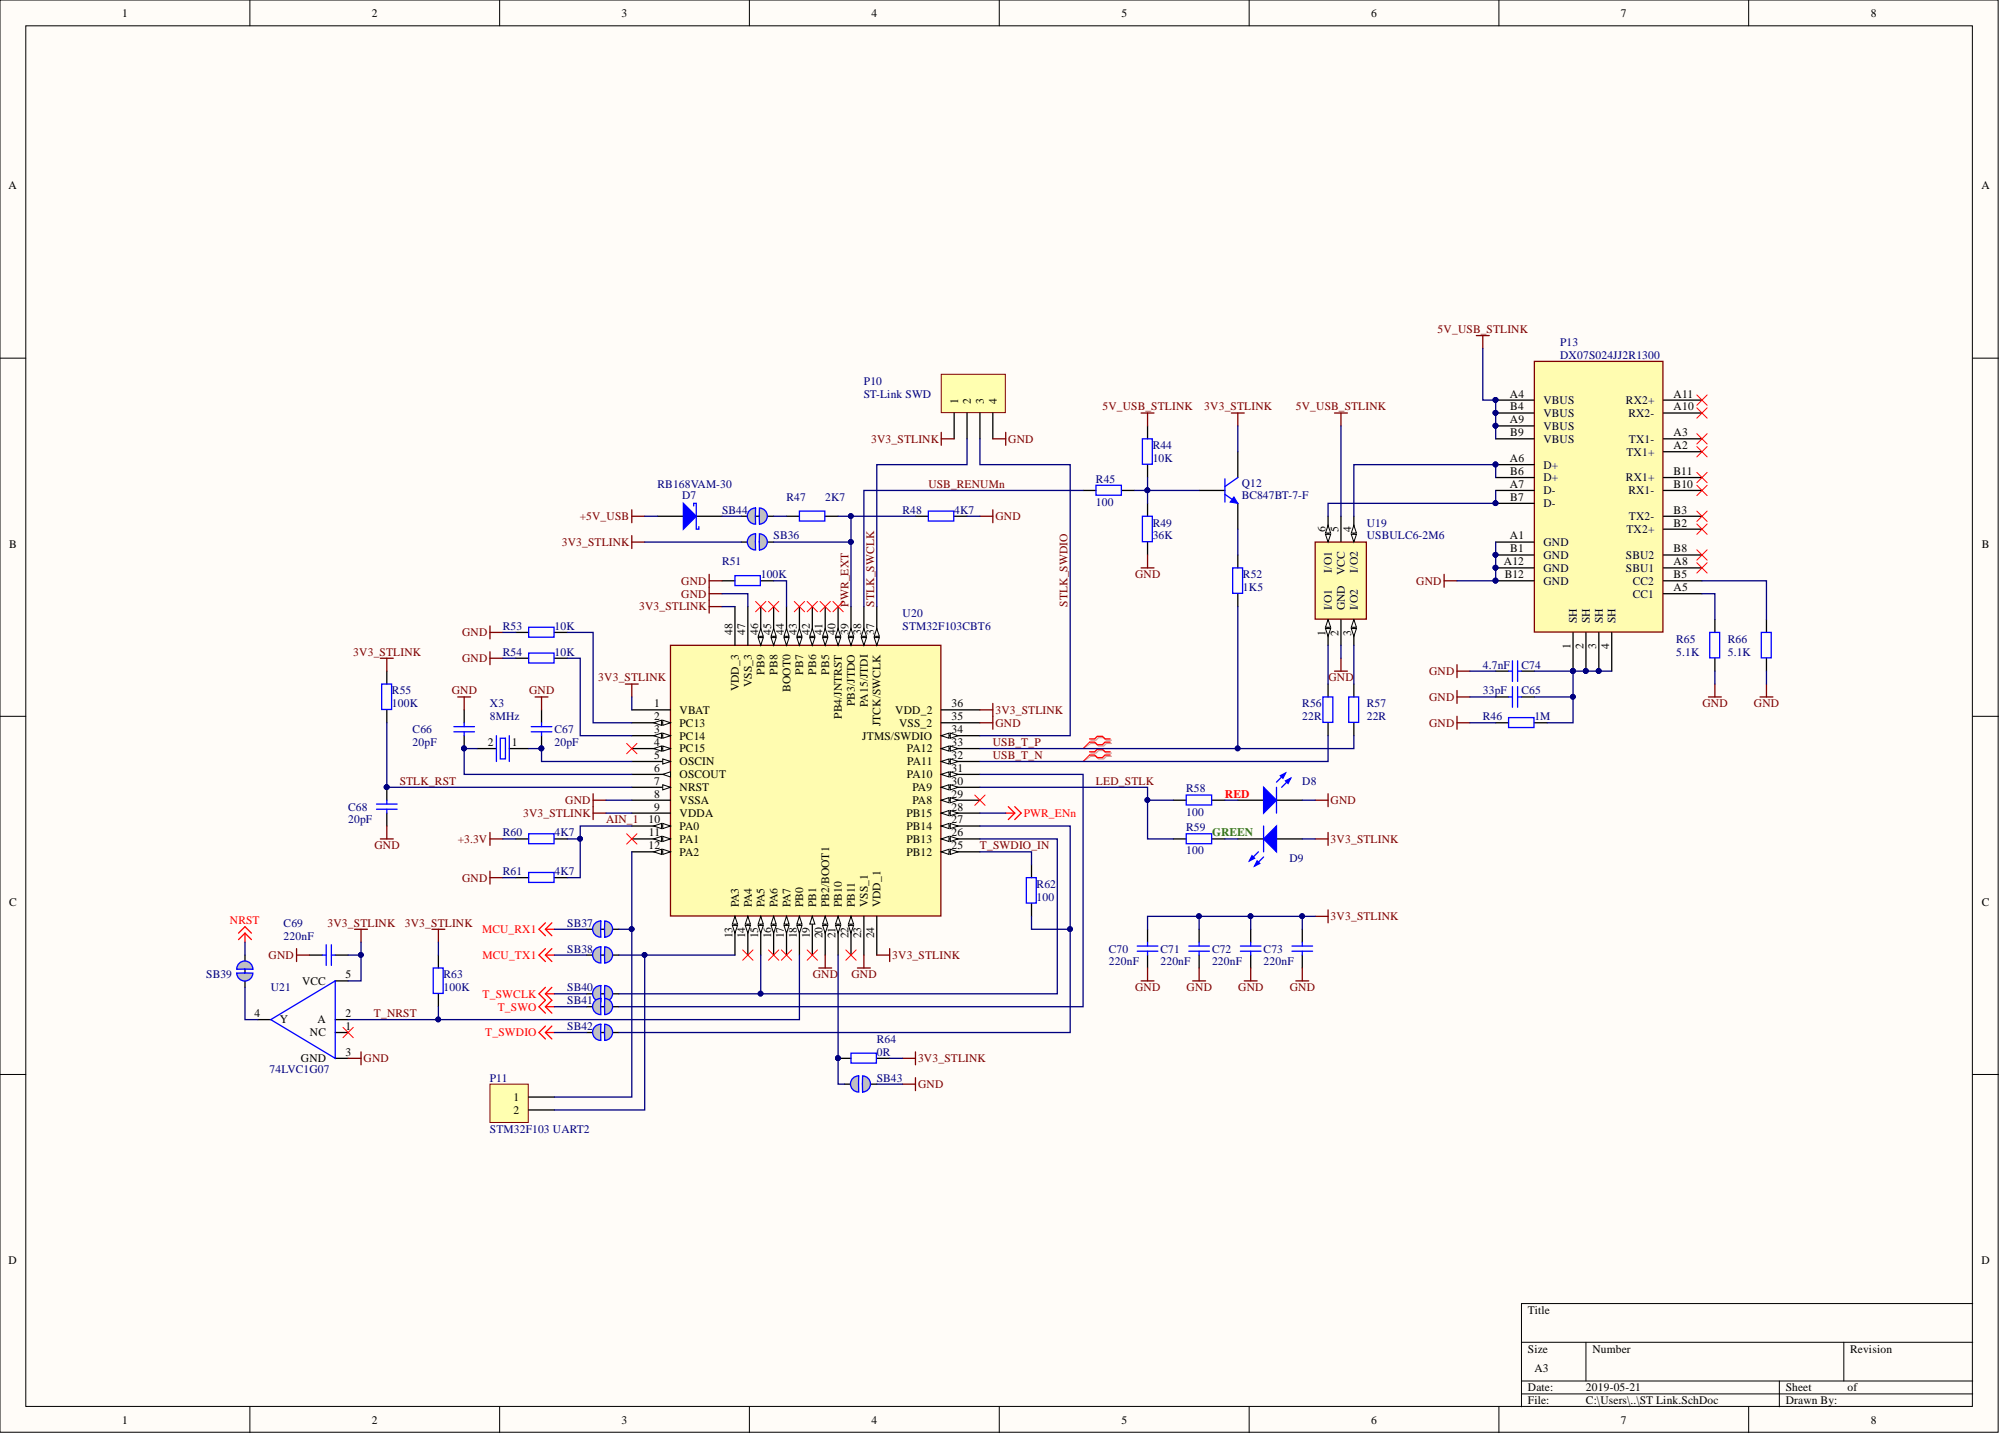
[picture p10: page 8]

GND A12 GND B1

OSCIN 5 | USB_T_N
OSCOUT 6
NRST 7 PA9 PB15 PB14 | 30
VSSA 8
VDDA 9 | 28 PWR_ENn 27
